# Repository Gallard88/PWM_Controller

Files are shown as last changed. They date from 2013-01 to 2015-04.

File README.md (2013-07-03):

PWM_Controller
==============

A 3 prong project.
Hardware, Firmware, and a Linux based daemon.

Hardware is based around an Atmel ATMega2560.
Communication is via USB.
Can control upto 16 PWM chanels. Each chanel times out  and disables
itself 7 seconds after it's last updated.
The system can measure it's current consumption, ambient temperature, and input voltage.
Library supplied to control via other software.

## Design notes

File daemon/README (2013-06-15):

PWM Controller Daemon

A daemon to communicate with the PWM_Controller PCB.

*** Notes ***

The Makefile cannot yet install the PWM_Controllerd script into the rc system.
This can be done manually by the command:

update-rc.d -f PWM_Controllerd defaults

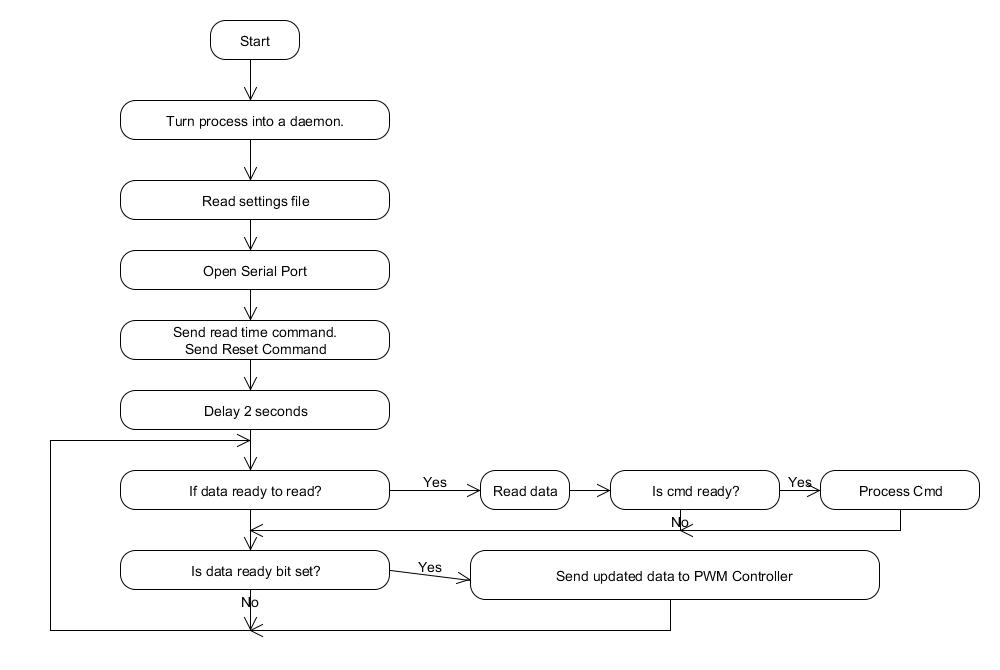
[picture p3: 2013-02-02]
FLowchart_Daemon.jpg

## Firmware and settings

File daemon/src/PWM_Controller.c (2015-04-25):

// *****************
#define _XOPEN_SOURCE

// *****************
#include <stdio.h>
#include <stdlib.h>
#include <string.h>
#include <syslog.h>
#include <unistd.h>
#include <signal.h>
#include <fcntl.h>
#include <sys/time.h>
#include <errno.h>

#include "PWM_Controller.h"
#include "Serial.h"
#include "Cmds_PWM.h"

// *****************
// Options
#define __DAEMONISE__    1

// *****************
const char PWM_Con_Settings_file[] = "/etc/PWM_Controller.conf";
static int Serial_fd;

#define SYSTEM_DELAY      10000   // us
static const struct timeval system_time = {0,SYSTEM_DELAY};
static char *PortName;

// *****************
static void System_Shutdown(void);
static void Check_Serial(int rv);

// *****************
void Connect_To_Port(void)
{
  Serial_fd = Serial_Openport(PortName, 115200, 0,0 );
  if ( Serial_fd < 0 )
    return;
  syslog(LOG_NOTICE, "Com Port %s connected", PortName);
  PWM_SetConnected();

  // send start up commands.
  // send temp update rate
  // send current update rate
  // send voltage update rate
	PWM_SetStartup(Serial_fd, 10);

	// force unit to restart
  PWM_Send_Restart(Serial_fd);
}

// *****************
void Run_CtrlC(int sig)
{
  exit(0);
}

// *****************
void Setup_SignalHandler(void)
{
  struct sigaction sig;

  // Install timer_handler as the signal handler for SIGVTALRM.
  memset (&sig, 0, sizeof (struct sigaction));
  sig.sa_handler = &Run_CtrlC;
  sigaction (SIGINT , &sig, NULL);
  sigaction (SIGTERM , &sig, NULL);
  sigaction (SIGABRT , &sig, NULL);

}

// *****************
int main(int argc, char *argv[])
{
  int loop = 1;
  int rv;
  fd_set readfds;
  struct timeval select_time;

  if ( argc != 2 ) {
    printf("Usage: PWM_Controller port\n");
    return -1;
  }

  openlog("PWM_Controller", LOG_PID , LOG_USER );
  syslog(LOG_NOTICE, "PWM_Controller Startup");
  PortName = argv[1];

  // register shutdown function.
  atexit(System_Shutdown);

  PWM_CreateSharedMemory();
  Setup_SignalHandler();

#ifdef __DAEMONISE__
  rv = daemon( 0, 0 );
  if ( rv < 0 ) {
    syslog(LOG_EMERG, "Daemonise failed" );
    exit(-1);
  }
#else
  printf("System starting - Debug mode\n");
#endif

  while ( loop > 0 ) {
    Connect_To_Port();
    while ( Serial_fd >= 0 ) {

      rv = PWM_Send_ChanelData( Serial_fd );
      Check_Serial(rv);

      FD_ZERO(&readfds);
      FD_SET(Serial_fd, &readfds);
      select_time = system_time;

      rv = select(Serial_fd+1, &readfds, NULL, NULL, &select_time);	// wait indefinately
      if ( rv < 0 )
        continue;

      if ( FD_ISSET(Serial_fd, &readfds) ) {
        // run receiver
        char readBuf[4096];
        int length = strlen(readBuf);

        rv = read(Serial_fd, readBuf + length, sizeof(readBuf) - length);
        Check_Serial(rv);

        if ( rv > 0 ) {
          readBuf[length + rv] = 0;

          while ( rv >= 0 ) {
            rv = CmdParse_ProcessString(Cmd_Table, readBuf, Serial_fd);
          }
        }
      }
    }
    sleep(60);
  }
  return 0;
}

// *****************
void Check_Serial(int rv)
{
  if ( rv < 0 ) {
    PWM_ClearSharedMemory();
    Serial_fd = Serial_ClosePort(Serial_fd);
    syslog(LOG_EMERG, "Serial coms lost, %d", errno);
  }
}

// *****************
static void System_Shutdown(void)
{
  PWM_ClearSharedMemory();
  syslog(LOG_NOTICE, "System shutting down");
  closelog();
}

// *****************
// *****************

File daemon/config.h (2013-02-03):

/* config.h.  Generated from config.h.in by configure.  */
/* config.h.in.  Generated from configure.ac by autoheader.  */

/* Name of package */
#define PACKAGE "pwm_controller"

/* Define to the address where bug reports for this package should be sent. */
#define PACKAGE_BUGREPORT "thomasburns88@gmail.com"

/* Define to the full name of this package. */
#define PACKAGE_NAME "PWM_Controller"

/* Define to the full name and version of this package. */
#define PACKAGE_STRING "PWM_Controller 1.0"

/* Define to the one symbol short name of this package. */
#define PACKAGE_TARNAME "pwm_controller"

/* Define to the home page for this package. */
#define PACKAGE_URL ""

/* Define to the version of this package. */
#define PACKAGE_VERSION "1.0"

/* Version number of package */
#define VERSION "1.0"

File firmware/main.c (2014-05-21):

// *****************************************************************************
/*
 *	PWM Controller.
 *	Compiler: ICC7 Pro.
 *	Target: ATMega 2560.
 *	Special Options.
 *	"Strings in FLASH only" = true
 *	PRINTF Version = long ( + long, and modifiers)
 *	Treat 'const' as '__flash' = true.
 *	Accept Extensions (C++ comments, binary constants) = true.
 *
	Last change: TB 2/02/2013 10:41:19 AM
 */
// *****************************************************************************

#include <iom2560v.h>
#include <string.h>
#include <stdio.h>

#include "Adc.h"
#include "conf_eeprom.h"
#include "eeprom.h"
#include "CmdProcessor.h"
#include "pwm.h"
#include "PWM_Cmds.h"
#include "timer.h"
#include "uart1.h"
#include "uart3.h"

// *****************************************************************************
/**

V1.4 --
Added timeout to PWM commands.

V1.5 -- 13 July 2013
Calibrated Voltage and Temp sensors
*/
// *****************************************************************************
const char Firmware_Version[] = "V 1.5";
const char Firmware_Date[] = __DATE__;
const char Firmware_Time[] = __TIME__;

// *****************************************************************************
#define LINEBUF_SIZE	256

char USB_LineBuf[LINEBUF_SIZE];
char Ext_LineBuf[LINEBUF_SIZE];
int Com_Timer;

// *****************************************************************************
void Run_USB_Serial(void)
{ // here every 10ms
  char str[100];
  int rv, cmd;
  int size;

  do
  {
    size = strlen(USB_LineBuf);
    rv = U1_RxGetLine( USB_LineBuf + size,  LINEBUF_SIZE - size );
    if ( rv < 0 )
      USB_LineBuf[0] = 0;
    else if ( rv > 0 )
    {
      if ( strlen(USB_LineBuf) )
      {
        cmd = Cmd_Lookup( USB_CmdTable, USB_LineBuf);
        if ( cmd >= 0 )
        {
          Com_Timer = 0;
//          U1_TxPutsf("OK\r\n");
        }
/*
        else
        {
          U1_TxPutsf("?>");
          U1_TxPuts(USB_LineBuf);
          U1_TxPutsf("<\r\n");
        }
*/
        USB_LineBuf[0] = 0;
      }
    }
  }
  while ( rv != 0 );
}

// *****************************************************************************
void Run_External_Serial(void)
{ // here every 10ms
  int rv;
  int size;

  do
  {
    size = strlen(Ext_LineBuf);
    rv = U3_RxGetLine( Ext_LineBuf + size,  LINEBUF_SIZE - size );
    if ( rv < 0 )
      Ext_LineBuf[0] = 0;
    else if ( rv > 0 )
    {
      Cmd_Lookup(Ext_CmdTable, Ext_LineBuf);
      Ext_LineBuf[0] = 0;
    }
  }
  while ( rv != 0 );
}

// *****************************************************************************
void IO_Init(void)
{
  //   76543210
  // 0bIOOIIIII
  DDRB = 0x60;
  PORTB = 0x00;

  //   76543210
  // 0b0000OI00
  DDRC = 0x01;
  PORTC = 0x01;

  //   76543210
  // 0b0000OI00
  DDRD = 0x04;
  PORTD = 0x0;

  //   76543210
  // 0b__OOO____
  DDRE = 0x38;
  PORTE = 0x00;

  //   76543210
  // 0bIIIIIIII
  DDRF = 0x00;
  PORTF = 0x00;

  //   76543210
  // 0b0000OI00
  DDRG = 0x03;
  PORTG = 0x3;

  //   76543210
  // 0b000000OI
  DDRJ = 0x02;
  PORTJ = 0x0;

  //   76543210
  // 0b0000OI00
  DDRK = 0x00;
  PORTK = 0x00;

  //   76543210
  // 0bIIOOOIII
  DDRL = 0x38;
  PORTL = 0x00;
}

// *****************************************************************************
void WDT_Prescaler_Change(void)
{// half second timeout.
  asm(" cli");
  asm("wdr");

  // Start timed equence
  WDTCSR |= (1<<WDCE) | (1<<WDE);
  // Set new prescaler(time-out) value = 64K cycles (~0.5 s)
  WDTCSR = (1<<WDE) | (1<<WDP2) | (1<<WDP1);
  asm(" sei");
}

// *****************************************************************************
#define TOGGLE_HEARTBEAT_LED()	PORTG ^= 0x1
#define START_POWER_LED()		PORTC ^= 0x1

// *****************************************************************************
int main( void )
{
  //-----------------------------------------------
  // initialise port pins.
  asm("wdr");
  IO_Init();
  asm("wdr");

  // start watchdog
  WDT_Prescaler_Change();

  //-----------------------------------------------
  // Initialise hardware.

  Timer_Init();	// Heart Beat Timer.

  ADC_Init();

  U1_Init ( 115200 );	// USB Coms.
  U3_Init ( 115200 );	// Expansion port.

  PWM_Initialise();

  //-----------------------------------------------
  // Initialise Sub-modules.
  PWM_Cmds_Init();

  //-----------------------------------------------
  Read_Firmware(NULL);
  START_POWER_LED();

  // Run main loop.
  for ( ; ; )
  {
    asm(" sei");
    asm("wdr");
    if ( Timer_Is10ms() )
    {
      // USB command handler
      Run_USB_Serial();

      // Expansion command handler
      Run_External_Serial();
    }

    if ( Timer_Is100ms() )
    {
      PWM_Cmds_Run();
    }
    if ( Timer_Is1s() )
    {
      TOGGLE_HEARTBEAT_LED();
	  PWM_RunTimer();
    }
  }
}

// *****************************************************************************
// *****************************************************************************

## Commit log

2013-01-20 Initial commit. Added PCB files
    new file: CPU.SchDoc
    new file: Contoller.PrjPcb
    new file: Controller.PcbDoc
    new file: PWM_Chanels.SchDoc
    new file: pOWER.SchDoc
    [CPU.SchDoc, Contoller.PrjPcb, Controller.PcbDoc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]
2013-01-25 Inital Firmware commit. Timer works, and system outputs a message every 1s via ftdi uart.
2013-01-26 System now prints temp and system current at a user configarable interval.
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2013-01-26 USB Cmd processor responds when a cmd is good or bad. added some code to receive the current measurements from the expansion board.
2013-01-28 Added UML diagram to explain how device works.
    new file: doc/Class_Diagram.jpg
    new file: doc/Class_Diagram.uxf
2013-01-28 Added Class diagram and flow chart
    new file: daemon/Class_Diagram.uxf
    new file: daemon/Flow_Chart.uxf
2013-02-02 Moved several functions over to PWM_Cmds.c System prints firmware upon start up.
2013-02-02 Added restart command. Added coms timeout code, default, 8 seconds. Re-added cmd processor for expansion board. Added watchdog to restart unit when problems occur. Made PWM run with a prescale of 8
    [PWM_Cmds.c, conf_eeprom.h, main.c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]
2013-02-02 Added basic source files for the Daemeon.
    new file: Class_Diagram_Daemon.jpg
    new file: FLowchart_Daemon.jpg
    new file: daemon/COPYING
    new file: daemon/INSTALL
    new file: daemon/Makefile
    new file: daemon/Makefile.am
    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
2013-02-03 Cleaned up git tracked files. Started building high level framework for Daemon.
    modified: ../.gitignore
    deleted: Makefile
    deleted: Makefile.in
    modified: aclocal.m4
    deleted: autom4te.cache/output.0
    deleted: autom4te.cache/output.1
    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
2013-02-03 Removed executables from git
    deleted: src/PWM_Controller
    deleted: src/PWM_Test
    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
2013-02-07 Calibrated Temp sensor.
    Sensor now reports the temperature correctly in degrees celcuis.
    Added code to ensure ADC ports are intialised correctly.
    [PWM_Cmds.c, main.c]
2013-02-08 Added Protocol document. Added code to print out system voltage.
2013-02-08 Fixed ADC driver, it can now read chanels 8 - 15.
    [adc.c]
2013-02-08 Changed offset to be pre and post; This made calculating the current value easier. Finished tuning current sensor. Fixed several IO port defs required to enable the outputs.
    [PWM_Cmds.c, adc.c, main.c]
2013-02-08 gitignore
    Added Pcb preivew file type to ignore list.
2013-02-09 Finished debugging the pwm driver. All 8 chanels now work. They run at 7.2 kHz, and have 8bit resolution.
2013-02-09 Fixed overflow issue in ADC Average filter.
    [adc.c]
2013-02-09 Fixed Voltage measurement scale factor.
    [PWM_Cmds.c]
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2013-02-11 Found a flaw in my logic, and corrected this. Ready to continue testing Cmd_Parse.
    modified: CmdParse.c
    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
    [PWM_Controller.c]
2013-02-12 Expansion port added
    Added and tested code to receive data from the expansion board.
2013-02-12 PWM Command
    PWM Cmd is now a 0 based index.
    Tested code that will echo a pwm command to the expansion board.
2013-02-15 Finished Command Parser.
    Cmd parser tested and working. Can extract data from a line of text, and look up the associated command.
    modified: Command_List.c
    modified: PWM_Controller.h
2013-02-15 New commands.
    Tested and verified the Voltage, Current and Temperature commands.
    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
2013-02-15 Started working on the Makefile scripts to make the program install correctly in the correct dirs.
    modified: src/Makefile
    modified: src/Makefile.am
    deleted: src/Makefile.in
    modified: src/PWM_Controller.c
    [PWM_Controller.c]
2013-02-15 Added conf file to install directory. PWM_Controller now works as a daemon.
    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
2013-02-15 Added Signal handler to catch ^C and termintaion signals. This will reset the data in the shred memory.
    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
    [PWM_Controller.c]
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2013-02-15 Added JSON tags to specify how often Volt, Current and Temp data should be sent. Added return value check to daemon()
2013-02-15 Changed PWM data to correctly send data as specificed by my protocol. Added range check to limit PWM duty cycles to between 0 - 1.
    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
    [PWM_Controller.c]
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2013-02-15 re-added PWM_Controller.SRC
    I discovered that this file is required by ICCV7 to correctly open the
    project.
2013-03-09 Added Code to stop the PWM from glitching when duty = 0
    Added code to disable PORT when duty = 0. This will stop the 1 count
    glitch that was occuring.
    [Contoller.PrjPcb]
2013-03-22 Fixed bug while writing PWM values to attached board. Re-wrote the code so it builds one long message, rather than lots of smaller messages, before writing to the serial port
    [PWM_Controller.c]
2013-03-25 Added compile flag for debugging slowed down timer tick from 35 -> 100 ms.
2013-03-25 fixed problem in debug code that printed the same line several times
    [PWM_Controller.c]
2013-03-26 added more debugging information
    Firmware now prints bad messages verbatim, as well as dumping PWM
    information when it arrives.
2013-03-27 Fixed bug that stopped PWM output from being correctly parsed by the hardware
    [PWM_Controller.c]
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2013-03-28 Fixed missing return value in PWM_Test
    [PWM_Test.c]
2013-03-28 Changed the system so the timer only fire while a serial port is connected. This should stop the sleep() func from waking prematurely
2013-03-28 Added code to limit the change in PWM output to +/- 5% Hopefully this will limit the power surge and noise generated by stating a motor, in some cases this has been enough to force the USB to re-enum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
2013-03-29 Fixed missed <<< from last merge
    [PWM_Controller.c]
2013-03-29 Fixed bug that stpeed the PWM_isConnected() function from worked. System was looking at the wrong flag
    [PWM_Lib.c]
2013-03-29 Fixed problem where lib could create shard mem segment even if PWM_Controller wasn't running.
    [PWM_Lib.c]
2013-03-29 Removed aclocal.m4 because it causes problems between the x86 pc and the arm pc
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2013-07-02 Send updated chanels. Added code to force system to only send a chanel if it has been set. This goes hand in hand with the chanel timeout in the hardware.
    modified: PWM_Lib.c
    modified: ShdMem.h
    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
2013-07-02 Added version info to make sure lib and program are in sync
    modified: ToDo
    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
2013-07-08 PWM Timeout
    Added a 7 second timeout to each channel. This will force a channel to
    turn off it if hasn't been updated recently.
2013-07-09 Configured system so that Shared Memory can be accessed by all users, This will make it easier when the PWM Daemon is running as root.
    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
2013-07-13 Temp bug fix
    fixed int overflow in temp sensor calculation
    [PWM_Cmds.c]
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2013-07-31 Voltage Monitor change
    Changed the 12V monitor resistor ratio.
    Amended firmware to reflect this.
    [Controller.PcbDoc, pOWER.SchDoc]
2013-11-23 Added new init script that should start/stop faster than the old one. However I cannot yet get it to automatically install.
    modified: ../Makefile.in
    modified: ../configure
    modified: ../configure.ac
    modified: Makefile.am
    modified: Makefile.in
    new file: PWM_Controller.sh
    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
2013-12-09 Added code to log PWM outputs to a file. Added logrotate script.
    modified: ../../.gitignore
    new file: PWM_Log.c
    new file: PWM_Logrotate
    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
2014-05-10 PWM Shared memory. Changed system to store motor data as an int, rather than float. Simplified logic to signal data ready.
    modified: Cmds_PWM.c
    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
2014-05-10 Revert "Hardcoded V/I/Temp update rate"
    This reverts commit 866bdd90f2c6cdbad8b15a2a03e96f147cd63473.
    [Cmds_PWM.c, PWM_Controller.c]
2014-05-10 Revert "PWM Shared memory."
    This reverts commit cc6b01ec77e7f997189cd49db147e4320247fbcb.
    This appear to reduce the stability of the system :(
    [Cmds_PWM.c, PWM_Lib.c, ShdMem.h]
2014-05-16 Removed JSON file. This conf file only contained a sinlge parameter of use, thus it made better sense to remove it and pass that parameter as an argument.
    deleted: PWM_Controller.conf
    modified: PWM_Controller.sh
    deleted: parson.c
    deleted: parson.h
    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
2014-05-21 Tidy up of PCB files.
    [CPU.SchDoc, Controller.PcbDoc, PWM_CON_CPU.SchDoc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]
2015-04-25 Removed PWM_Log This fucntionality is better handled by external programs.
    deleted: PWM_Log.c
    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
2015-04-25 Better locking. Added function to read three measurements in a single operation. This will save several lock/unlock cycles.
    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
